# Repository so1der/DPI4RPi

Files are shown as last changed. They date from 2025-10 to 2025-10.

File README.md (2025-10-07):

# DPI4RPi

# README:  [Українська](#DPI4RPi-українська) 

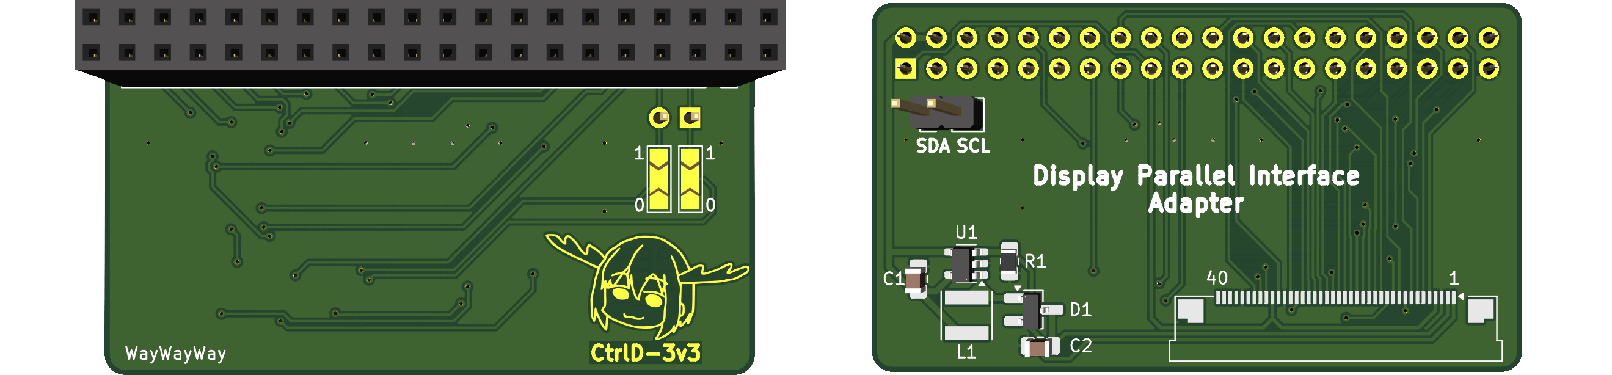
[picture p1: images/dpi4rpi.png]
DPI4RPi


**DPI4RPi** is an adapter board designed to connect displays with a DPI (Display Parallel Interface) bus to the Raspberry Pi. This bus is often found in inexpensive displays, such as those from navigation devices, cameras, portable gaming consoles, etc.

The board has been personally tested by me with the T43P12 display.

The board includes a circuit for powering the display’s backlight, with a voltage of **36V** and a current of **20 mA** (approximately up to 8 series connected LEDs). 

> **WARNING:** The circuit does not have an open-circuit protection, so do not connect the board without a display.

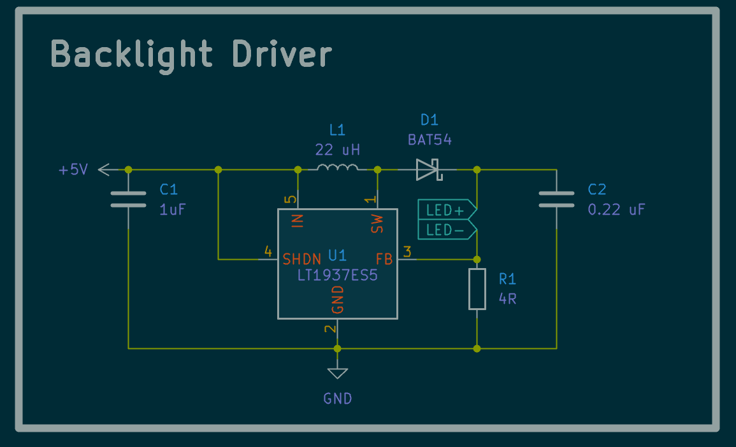
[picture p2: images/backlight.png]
Backlight driver


The board also features jumpers for HSYNC/VSYNC – some displays can work without them, which frees up the I2C bus. To use HSYNC and VSYNC - short both jumpers to position 1. To use I2C, short both jumpers to position 0 – this will ground the HSYNC and VSYNC, allowing the I2C to be used from the appropriate pins on the board.

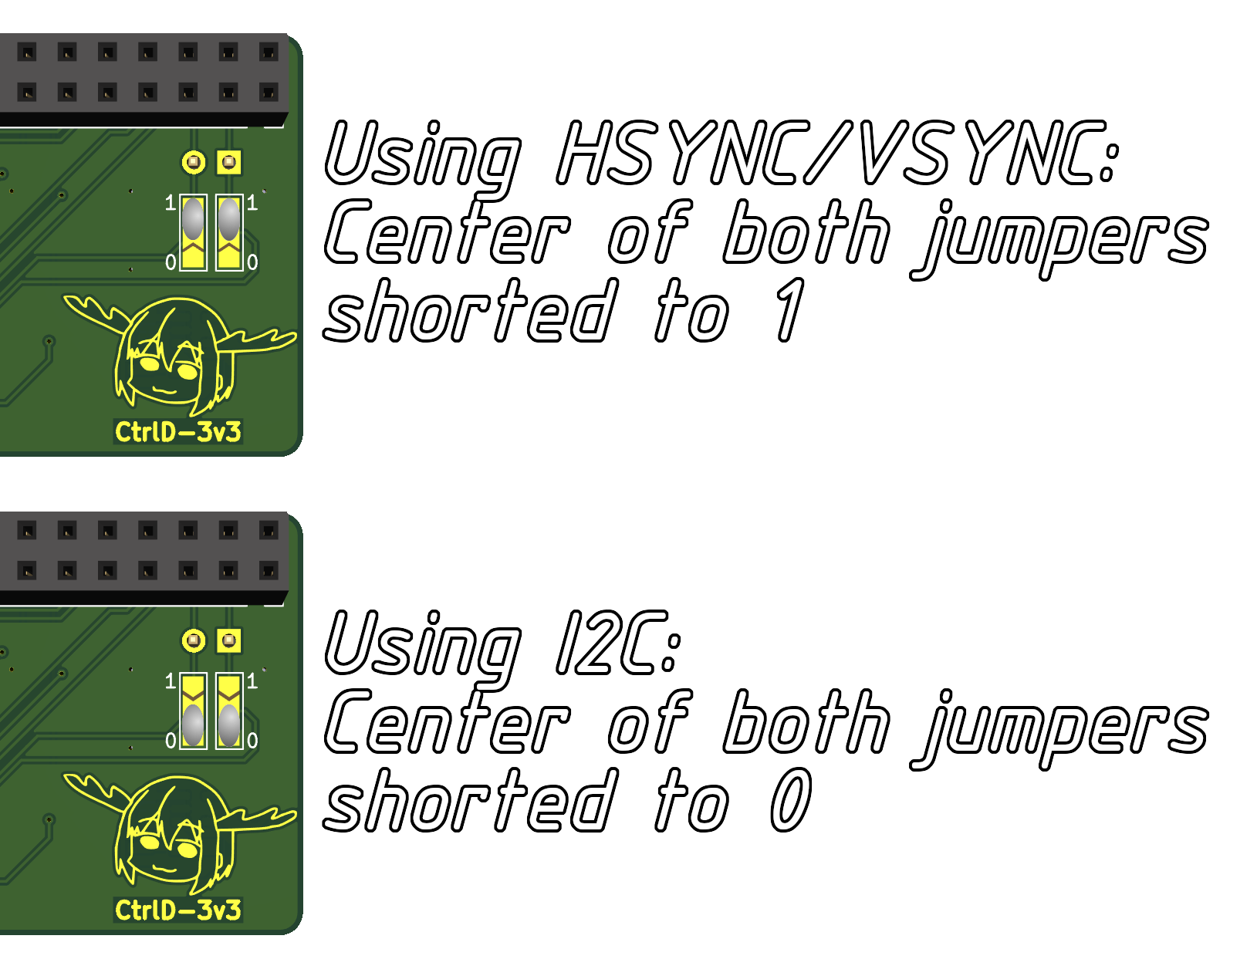
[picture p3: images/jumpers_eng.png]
HSYNC/VSYNC jumpers


---

### Some details about the board:

- Resistors and capacitors are of 0805 package size.
- Inductor size: 4x4mm.
- Diode: BAT54 in SOT-23 package.
- Backlight power IC: LT1937ES5, in TSOT-23 package.
- Display connector: 40-pin FPC, 0.5mm pitch, contacts located ON TOP.
- Raspberry Pi connector: 2x20 pin, 2.54mm pitch.

---

Additionally, you will need to configure the Raspberry Pi to work with DPI. To do this, you need to edit the `/boot/config.txt` file. For more detailed information, you can refer to the following links: [this](https://so1der.github.io/articles/rgb888-to-rpi.html#raspberry-pi-setup) and [this](https://www.zephray.me/post/rpi_dpi/).

Example of use (the board looks a little different in the photos because this is the first revision with some errors that I later fixed):

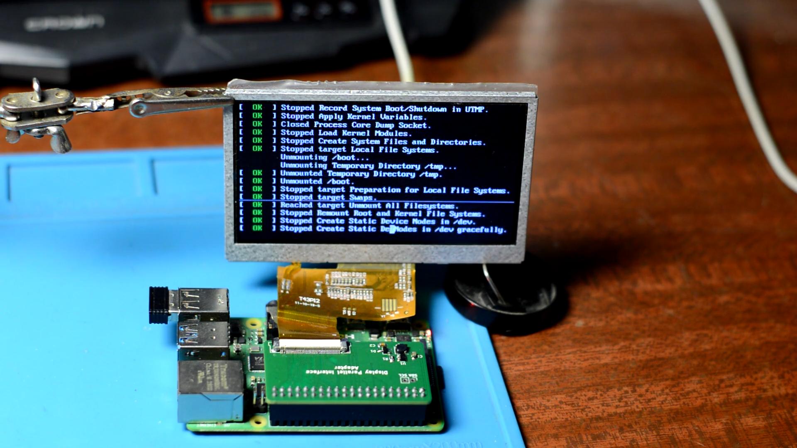
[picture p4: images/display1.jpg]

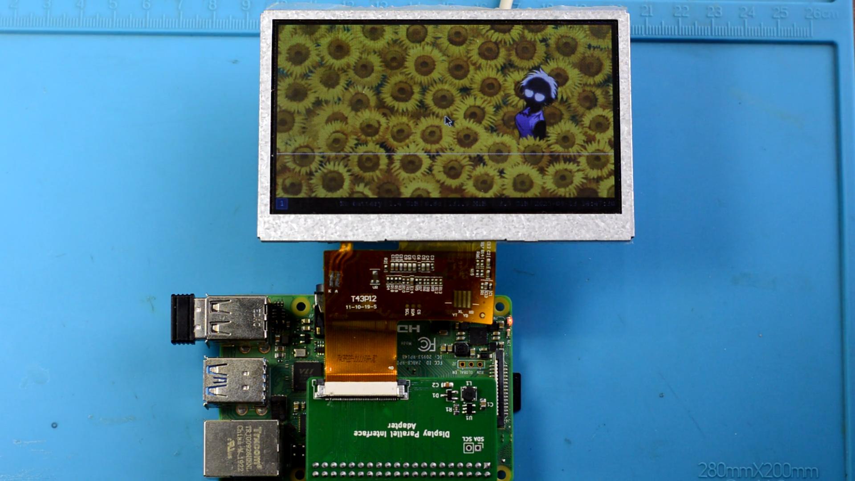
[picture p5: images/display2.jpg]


---

# DPI4RPi Українська:
DPI4RPi

**DPI4RPi** це плата-адаптер, для підключення дисплеїв з шиною DPI (Display Parallel Interface) до Raspberry Pi. Така шина часто зустрічається в дешевих дисплеях, наприклад з навігаторів, камер, портативних ігрових консолей, тощо.

Плата була протестована особисто мною з дисплеєм T43P12.

На платі присутня схема для живлення підсвітки дисплея напругою **36В** та струмом **20 мА** (приблизно 8 послідовно з'єднаних світлодіодів). 

> **УВАГА:** схема не має захисту від розриву кола, тож не підключайте плату без дисплея.

Backlight driver

Також на платі присутні перемички для HSYNC/VSYNC - деякі дисплеї можуть працювати без них, що дозволяє звільнити шину I2C. Щоб використовувати HSYNC та VSYNC - замкніть обидві перемички в положення 1. Щоб використовувати I2C - замкніть обидві перемички в положення 0 - це заземлить HSYNC та VSYNC, і дасть змогу використовувати I2C з відповідних контактів на платі.

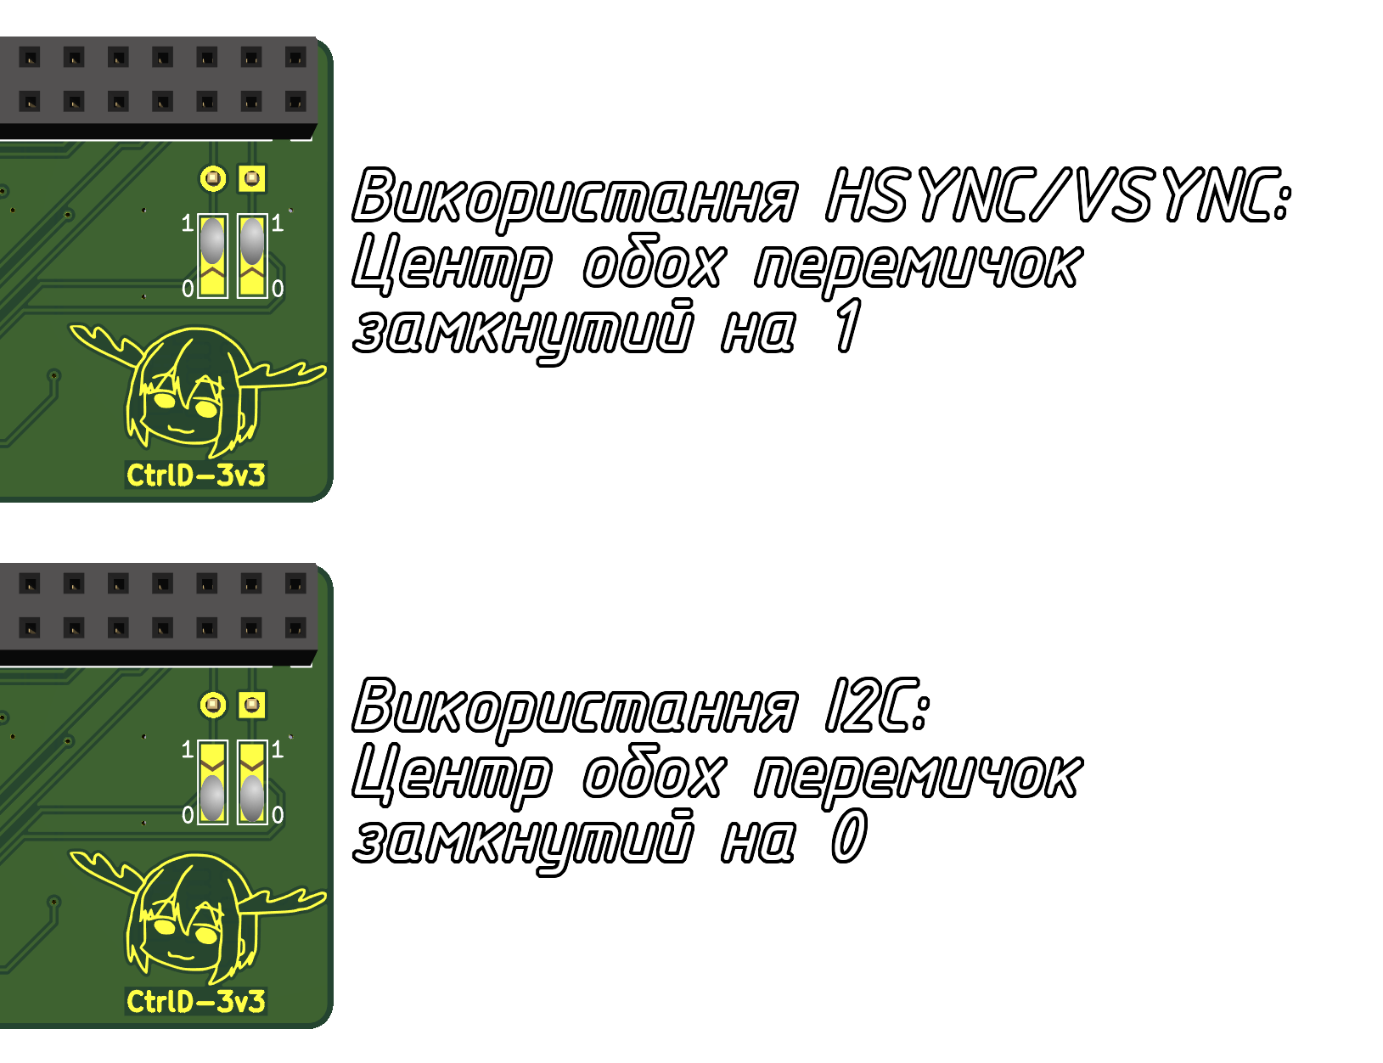
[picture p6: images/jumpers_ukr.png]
HSYNC/VSYNC jumpers


---

### Деякі моменти стосовно плати:

- Резистори та конденсатори використані типорозміру 0805.
- Розмір дроселя: 4х4мм.
- Діод: BAT54 в корпусі SOT-23.
- Мікросхема для живлення підсвітки: LT1937ES5, в корпусі TSOT-23.
- Коннектор для дисплея: 40 pin FPC, крок 0.5мм, контакти розташовані ВГОРІ.
- Коннектор для Raspberry Pi: 2x20 pin, крок 2.54мм.

---

Також слід налаштувати Raspberry Pi на роботу з DPI. Для цього треба редагувати файл `/boot/config.txt`. Більш детально можна почитати за [цим](https://so1der.github.io/articles/rgb888-to-rpi.html#raspberry-pi-setup) а також [цим](https://www.zephray.me/post/rpi_dpi/) посиланнями.

Приклад використання (на фотографіях плата трішки відрізняється, бо це перша ревізія з деякими помилками, які я в подальшому виправив):




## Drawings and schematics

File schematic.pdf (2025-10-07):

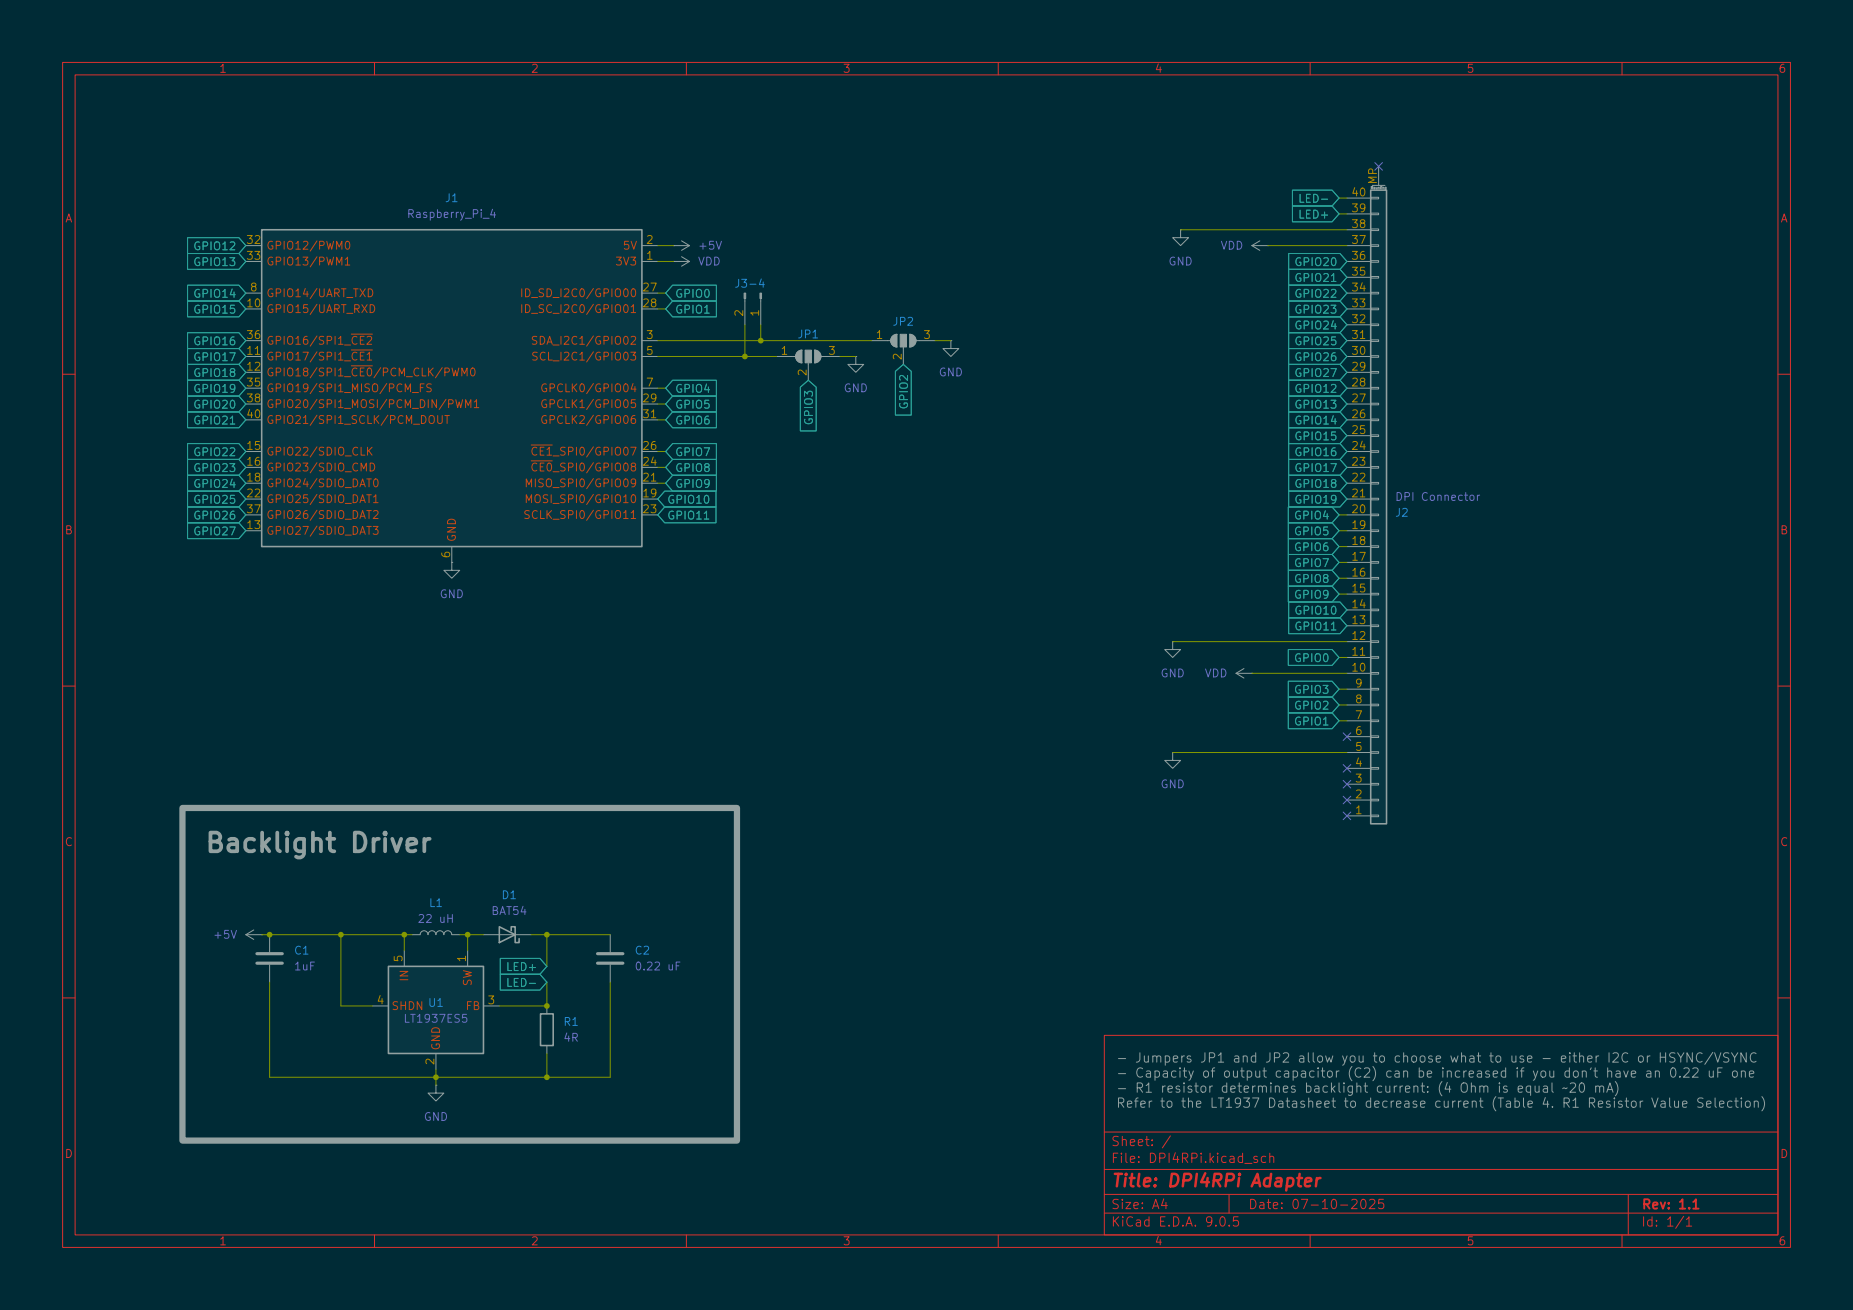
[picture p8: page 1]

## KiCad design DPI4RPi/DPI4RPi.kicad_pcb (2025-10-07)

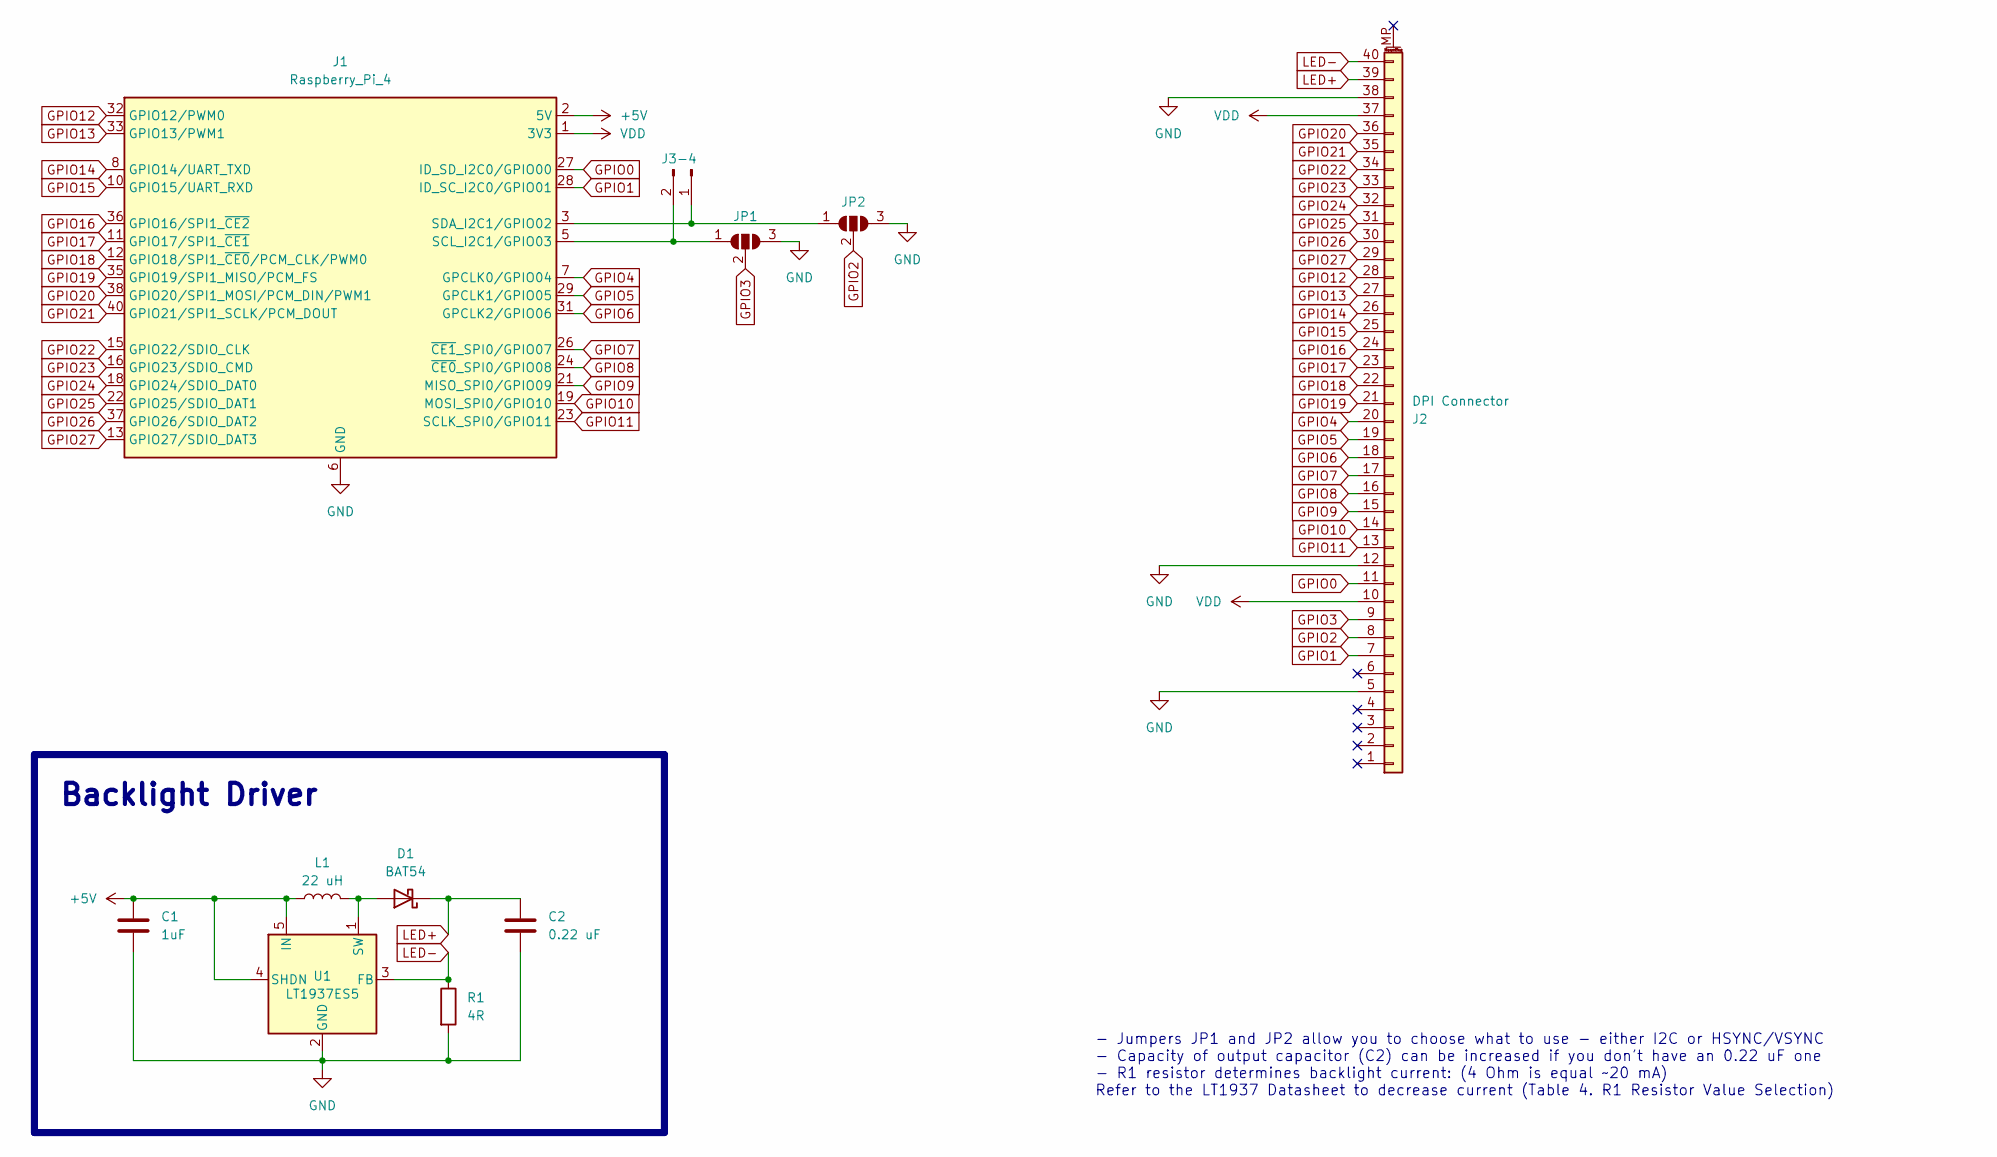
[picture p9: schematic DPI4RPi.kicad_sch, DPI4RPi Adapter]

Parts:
C1: 1uF; C_0805_2012Metric_Pad1.18x1.45mm_HandSolder
C2: 0.22 uF; C_0805_2012Metric_Pad1.18x1.45mm_HandSolder
D1: BAT54; SOT-23_Handsoldering
J1: Raspberry_Pi_4; PinSocket_2x20_P2.54mm_Vertical
J2: DPI Connector; Amphenol_F32Q-1A7x1-11040_1x40-1MP_P0.5mm_Horizontal
J3-4: Conn_01x02_Pin; PinHeader_1x02_P2.54mm_Vertical
JP1, JP2: SolderJumper_3_Open; SolderJumper-3_P2.0mm_Open_TrianglePad1.0x1.5mm_NumberLabels
L1: 22 uH; L_Vishay_IFSC-1515AH_4x4x1.8mm
R1: 4R; R_0805_2012Metric_Pad1.20x1.40mm_HandSolder
U1: LT1937ES5; SOT-23-5

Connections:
+5V: C1.1, J1.2 (5V), J1.4 (5V), L1.1, U1.4 (SHDN), U1.5 (IN)
GND: C1.2, C2.2, J1.6 (GND), J1.9 (GND), J1.14 (GND), J1.20 (GND), J1.25 (GND), J1.30 (GND), J1.34 (GND), J1.39 (GND), J2.5, J2.12, J2.38, JP1.3 (B), JP2.3 (B), R1.2, U1.2 (GND)
GPIO0: J1.27 (ID_SD_I2C0/GPIO00), J2.11
GPIO1: J1.28 (ID_SC_I2C0/GPIO01), J2.7
GPIO2: J2.8, JP2.2 (C)
GPIO3: J2.9, JP1.2 (C)
GPIO4: J1.7 (GPCLK0/GPIO04), J2.20
GPIO5: J1.29 (GPCLK1/GPIO05), J2.19
GPIO6: J1.31 (GPCLK2/GPIO06), J2.18
GPIO7: J1.26 (~CE1_SPI0/GPIO07), J2.17
GPIO8: J1.24 (~CE0_SPI0/GPIO08), J2.16
GPIO9: J1.21 (MISO_SPI0/GPIO09), J2.15
GPIO10: J1.19 (MOSI_SPI0/GPIO10), J2.14
GPIO11: J1.23 (SCLK_SPI0/GPIO11), J2.13
GPIO12: J1.32 (GPIO12/PWM0), J2.28
GPIO13: J1.33 (GPIO13/PWM1), J2.27
GPIO14: J1.8 (GPIO14/UART_TXD), J2.26
GPIO15: J1.10 (GPIO15/UART_RXD), J2.25
GPIO16: J1.36 (GPIO16/SPI1_~CE2), J2.24
GPIO17: J1.11 (GPIO17/SPI1_~CE1), J2.23
GPIO18: J1.12 (GPIO18/SPI1_~CE0/PCM_CLK/PWM0), J2.22
GPIO19: J1.35 (GPIO19/SPI1_MISO/PCM_FS), J2.21
GPIO20: J1.38 (GPIO20/SPI1_MOSI/PCM_DIN/PWM1), J2.36
GPIO21: J1.40 (GPIO21/SPI1_SCLK/PCM_DOUT), J2.35
GPIO22: J1.15 (GPIO22/SDIO_CLK), J2.34
GPIO23: J1.16 (GPIO23/SDIO_CMD), J2.33
GPIO24: J1.18 (GPIO24/SDIO_DAT0), J2.32
GPIO25: J1.22 (GPIO25/SDIO_DAT1), J2.31
GPIO26: J1.37 (GPIO26/SDIO_DAT2), J2.30
GPIO27: J1.13 (GPIO27/SDIO_DAT3), J2.29
LED+: C2.1, D1.3 (K), J2.39
LED-: J2.40, R1.1, U1.3 (FB)
unnamed: D1.1 (A), L1.2, U1.1 (SW)
unnamed 33: J1.5 (SCL_I2C1/GPIO03), J3-4.2, JP1.1 (A); also elsewhere on the board
unnamed 34: J1.3 (SDA_I2C1/GPIO02), J3-4.1, JP2.1 (A); also elsewhere on the board
VDD: J1.1 (3V3), J1.17 (3V3), J2.10, J2.37

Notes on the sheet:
- Jumpers JP1 and JP2 allow you to choose what to use - either I2C or HSYNC/VSYNC - Capacity of output capacitor (C2) can be increased if you don't have an 0.22 uF one - R1 resistor determines backlight current: (4 Ohm is equal ~20 mA) Refer to the LT1937 Datasheet to decrease current (Table 4. R1 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
Backlight Driver

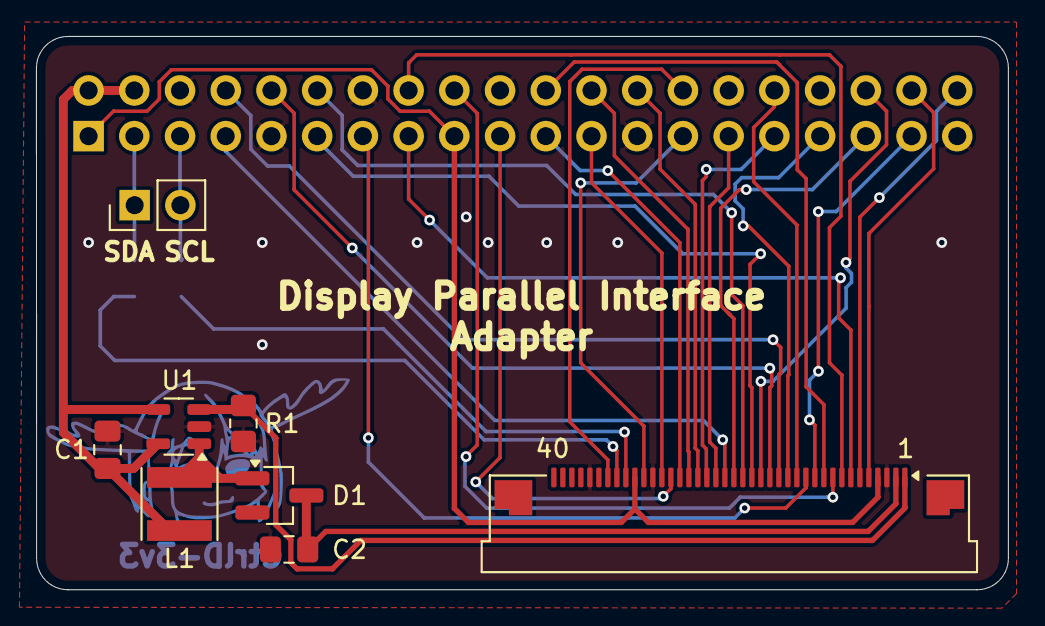
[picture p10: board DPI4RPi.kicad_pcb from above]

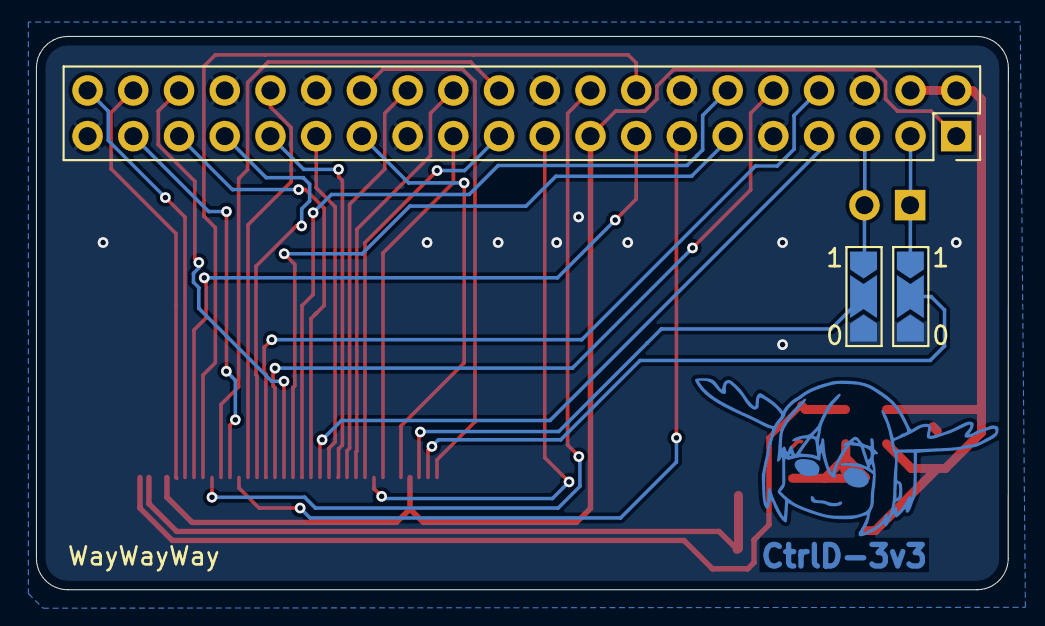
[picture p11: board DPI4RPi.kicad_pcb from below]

Board: 2 copper layers, 54.0 x 30.7 mm, 11 parts (3 on the bottom side), 36 nets.

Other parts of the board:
J3: Conn_01x02_Pin; PinHeader_1x02_P2.54mm_Vertical

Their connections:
unnamed 33: J3.2; also elsewhere on the board
unnamed 34: J3.1; also elsewhere on the board
